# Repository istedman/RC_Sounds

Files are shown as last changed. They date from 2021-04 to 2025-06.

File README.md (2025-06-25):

# RC Sounds
A simple, low cost sound effect module for R/C vehicles, land or water based. It utilises a DF Robot DFR0299 MP3 module to continuously play a selected MP3 sound file. A Microchip ATTiny85 provides MP3 control functions, error handling and can support two servo PWM inputs. A set of 4 switches are used to provide easy selection of the desired sound sample. Using one of the PWM inputs, a horn/siren sound can be overlaid and once it finishes playing, normal sound resume. The horn/siren setting is programmable to allow for different receiver outputs.

A PAM8403 Class D amplifier, with EMC fixes is also provided, this allows the system to drive 2x 8 ohm speakers at 2W. Volume control is provided on-board as well as an option to mute the amplifier and finally use an external amplifier, if desired using the pre-amp outputs.

PCB designed to fit into a Hammond 1594B enclosure.
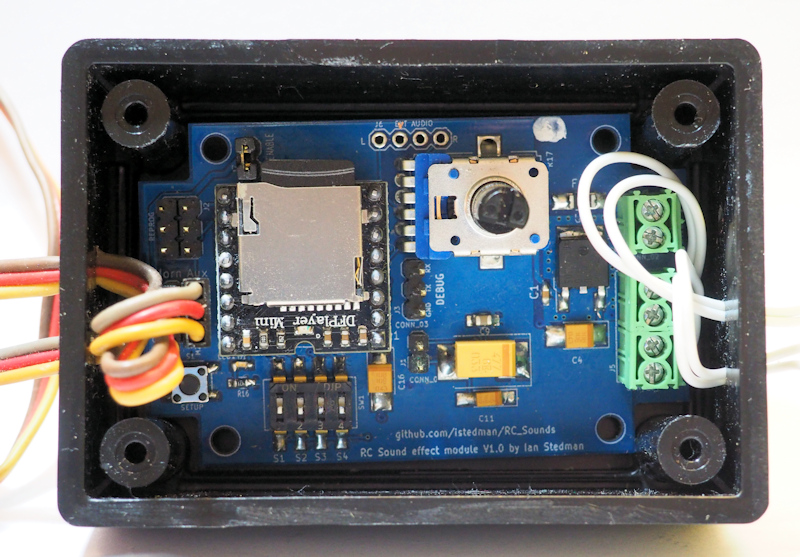
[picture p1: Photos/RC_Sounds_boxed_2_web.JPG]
Boxed unit


Total cost of all parts, PCB, enclosure and speakers is approximately £30. See the BOM directory for an HTML export with full ordering part numbers.

## Current state as of 25th June 2025.
Design is working well. Has based compatibility tests with multiple AM/2.4 GHz receivers, 2-6 channels and has been field tested.

Use the updated V1.2_1_int software, this adds 4 speeds to the engine sounds and utilises the auxilary input to act as the throttle. The software is written in the Arduino IDE, it uses the ATtinyCore library and no bootloader. The board must be programmed using a progammer, I use a USBASP. To allow the PWM settings function to work, you have to disable the reset function on the fuses. A high voltage programmer is required to unlock. I use this design, https://github.com/wokwi/attiny-hvsp-programmer and clip onto the ATTiny85. All fuse setting defined in the software.

ATTiny85 fuse settings are in the header of the main source code, use USBASP/Avrdudess to set them.

## Boat sound effects SD card image now available

My example SD card image, for boats has now been uploaded to the repository.

## Powering the design

Power is from a 3.7-12V supply or the receiver BEC circuit. Unit has a polyfuse to protect against reverse polarity and a linear regulator.
Do not use with a 1S LiPO ESC or any other ESC that boosts the BEC output. The current design assumes the stndard +5V BEC output voltage. My 1S LiPO ESCs output
6 or 7.2V to boost the servo power, using such an ESC (Trackstar Gen II 120A or Hobbywing Xerun) would irreprably damage the design as it will operate with 5.5V maximum.

You will need an UltraBEC/SuperBEC ESC, i.e. one that can output 2A @ 5V for reliable operation. This unit can demand a peak 0.6A @ 5V, when tested with a 1A BEC, and 3-4 servos, I had a few brownouts. If it reandomly resets at the same time as your receiver, use the external power option and remove the BEC jumper!

## Schematic and circuit description

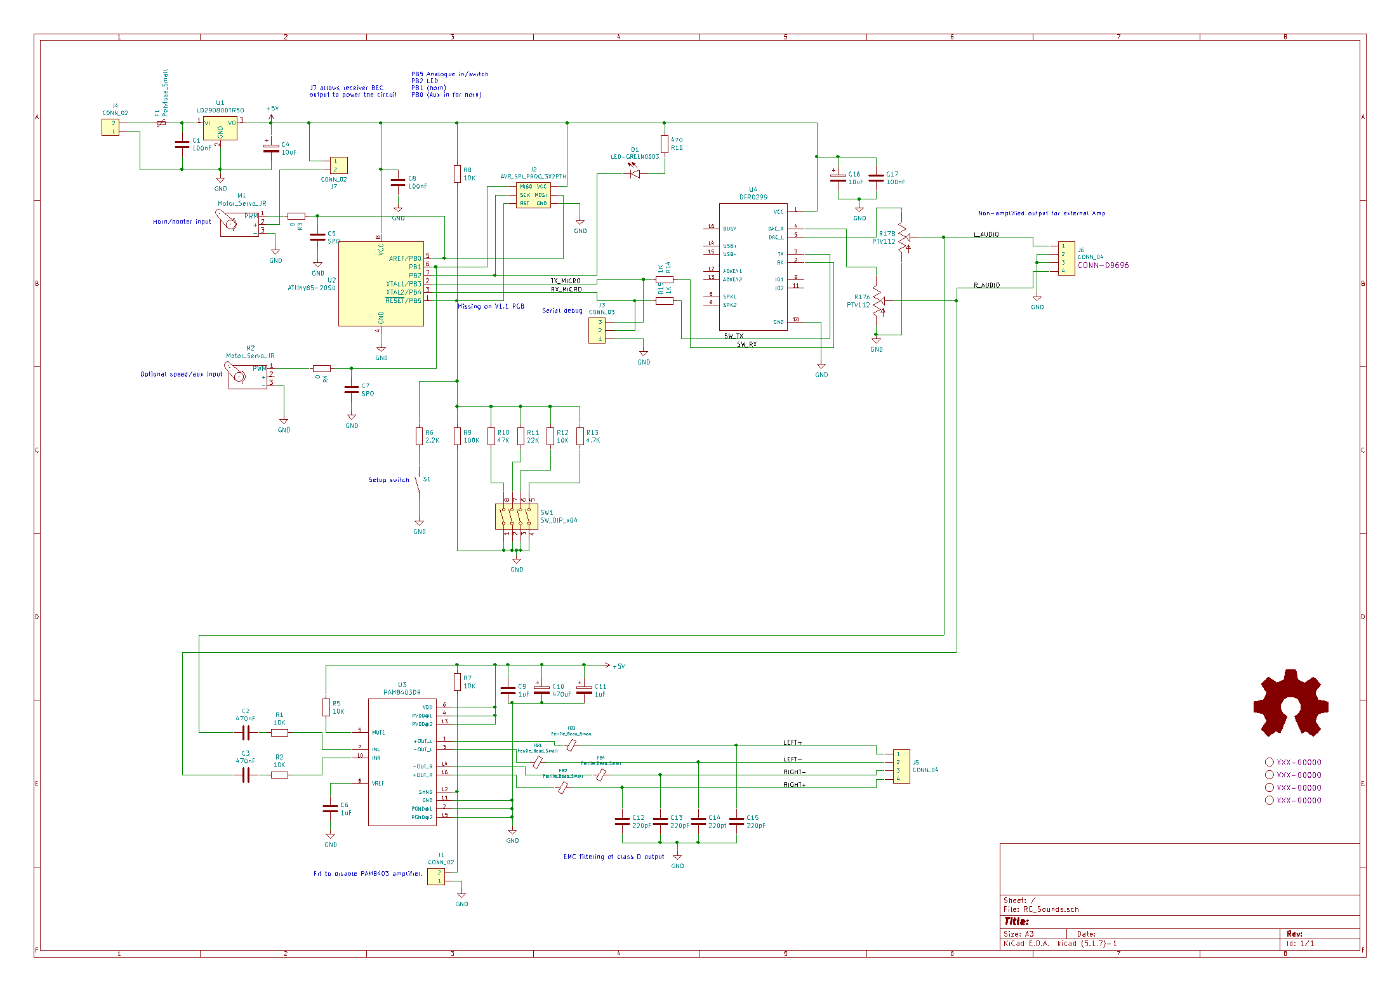
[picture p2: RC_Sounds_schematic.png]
Schematic


Power comes from the 5V BEC output of the ESC, if you fit a jumper on J7 of from a 3.7-12V source via J2, using appropriate wire. Connections via J2 have a 1.1A polyfuse and a LD29080-5 5V, 800mA LDO regulator, which provde revers polarity protection.

The ATTiny 85 microcontroller provides the control function. It reads the PWM inputs from two receiver channels, the horn/hooter input connects to pin 5 and the throttle input connects to pin 6. 

Communications to/from the DFR0299 MP3 module are via pins 2 & 3 and use a standard 9600 8N1 serial interface. A USB to TTL adaptor can be connected to the TX output of the ATTiny 85 on pin 2 for debug messages, using J3.

A solitary LED, D1 is used to setup functions and when the horn has been activated.

A set of DIP switches, SW1, set various analogue voltages that determine the sound sample to be played. Limits are defined in the software. A setup switch, S1 is used in the setup routine to set the horn on/off position and the throttle positions.

The DAC output of the DFR0299 is connected, via a dual gang audio potentiometer R17A/B to a PAM8403 audio amplifier. J6 provides a pre-amplifier output.
The DFR0299 DAC outputs, post volume control are AC coupled via C2 and C3. Connector J1 can be used to mute the amplifier. Capacitor C10, a 47uF capacitor, is to reduce the effects of the amplifier on the power supplies. I have added the recommended filter circuit to the output stage, using FB1-FB4 and C12-C15, this reduces radio emissions in the region of 25-40 MHz, important for RC usage as there are still some 27 and 40 MHz systems around.

Into 8 ohm speakers the design can deliver 1.8W. Peak power i've observed has been close to 2W.

A photo of the PCB
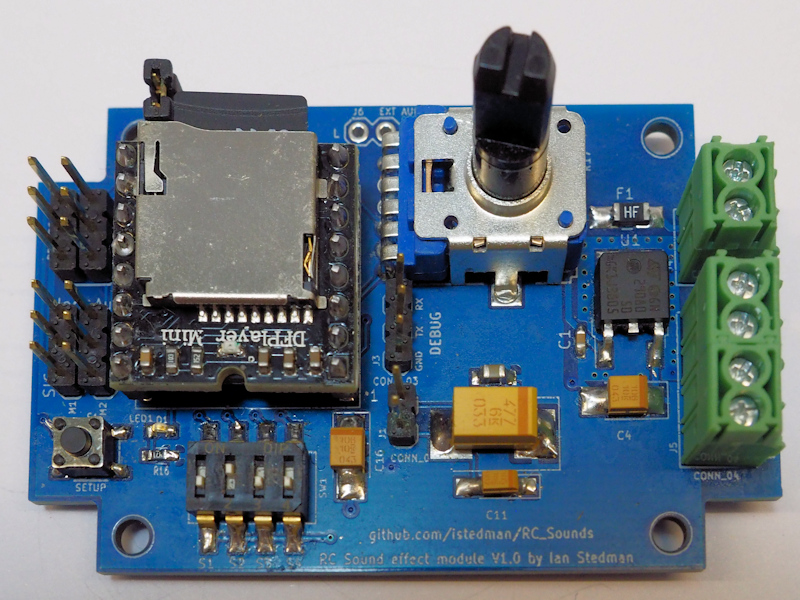
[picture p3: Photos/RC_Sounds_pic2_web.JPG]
Just the PCB


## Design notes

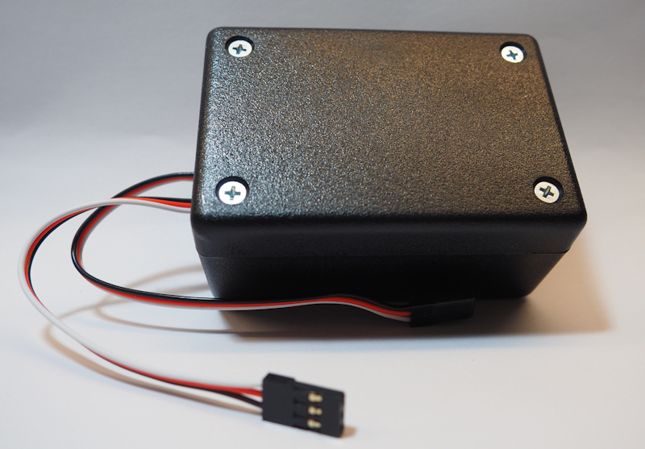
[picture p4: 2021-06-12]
Photos/RC_Sounds_boxed_1_web.JPG

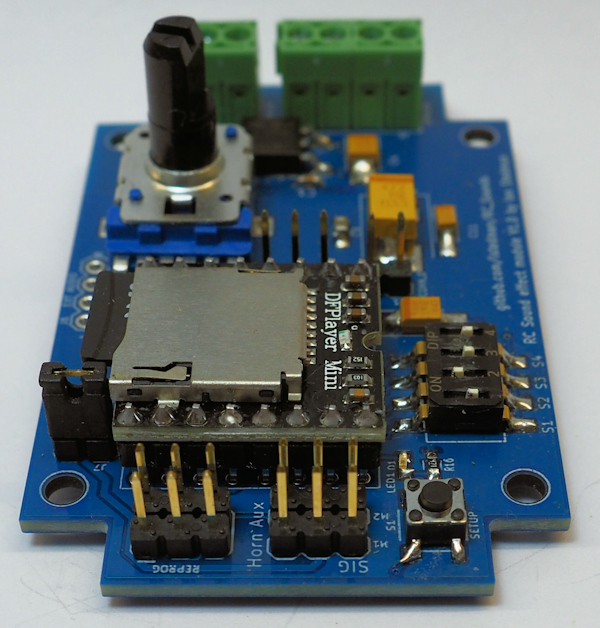
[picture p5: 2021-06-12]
Photos/RC_Sounds_pic3_web.JPG

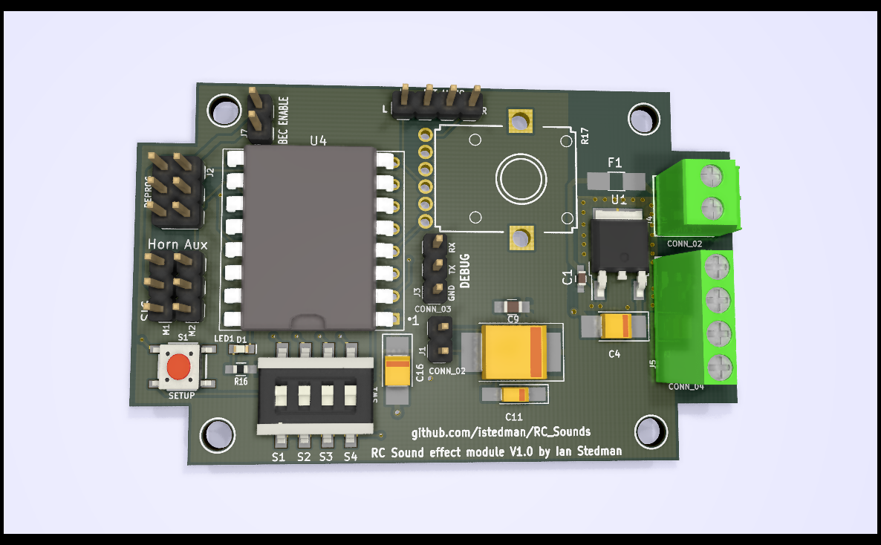
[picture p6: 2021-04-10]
RC_Sounds_3d_PCB.png

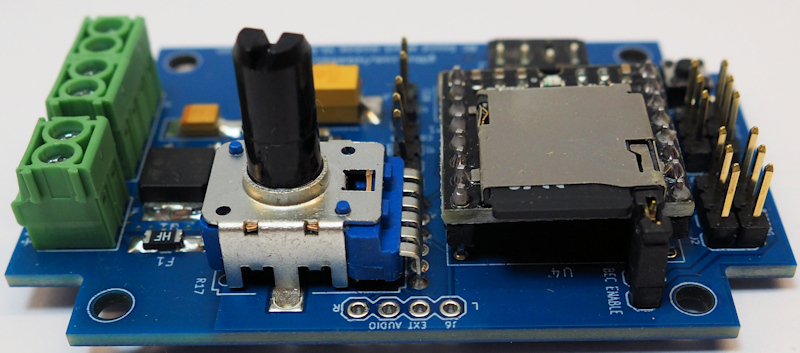
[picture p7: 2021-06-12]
Photos/RC_Sounds_pic1_web.JPG

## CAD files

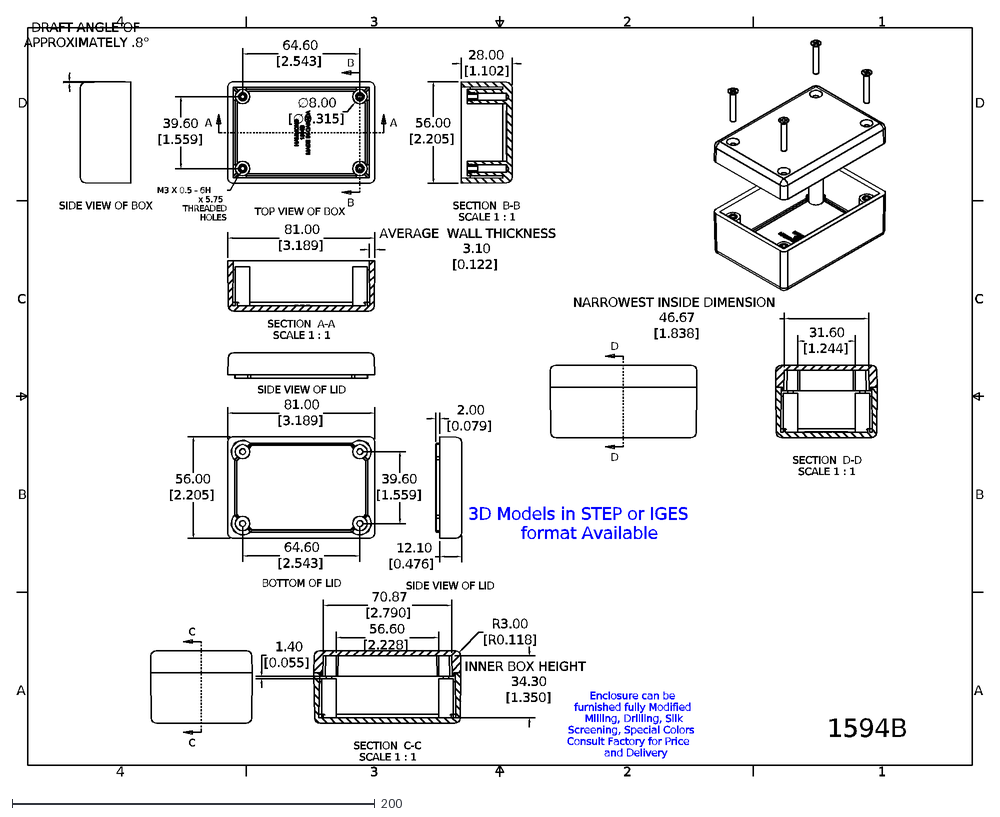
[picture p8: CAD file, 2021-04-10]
1594B.dxf
TOP VIEW OF BOX
BOTTOM OF LID
SIDE VIEW OF BOX
A
SECTION A-A
SCALE 1 : 1
B
SECTION B-B
64.60
[2.543]
39.60
[1.559]
∅8.00
[∅0.315]
DRAFT ANGLE OF
APPROXIMATELY .8°
81.00
[3.189]
AVERAGE WALL THICKNESS
3.10
[0.122]
56.00
[2.205]
28.00
[1.102]
SIDE VIEW OF LID
M3 X 0.5 - 6H
x 5.75
THREADED
HOLES
2.00
[0.079]
12.10
[0.476]
C
SECTION C-C
1.40
[0.055]
56.60
[2.228]
70.87
[2.790]
INNER BOX HEIGHT
34.30
[1.350]
R3.00
[R0.118]
D
SECTION D-D
31.60
[1.244]
NARROWEST INSIDE DIMENSION
46.67
[1.838]
1
2
3
4
1594B
Enclosure can be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

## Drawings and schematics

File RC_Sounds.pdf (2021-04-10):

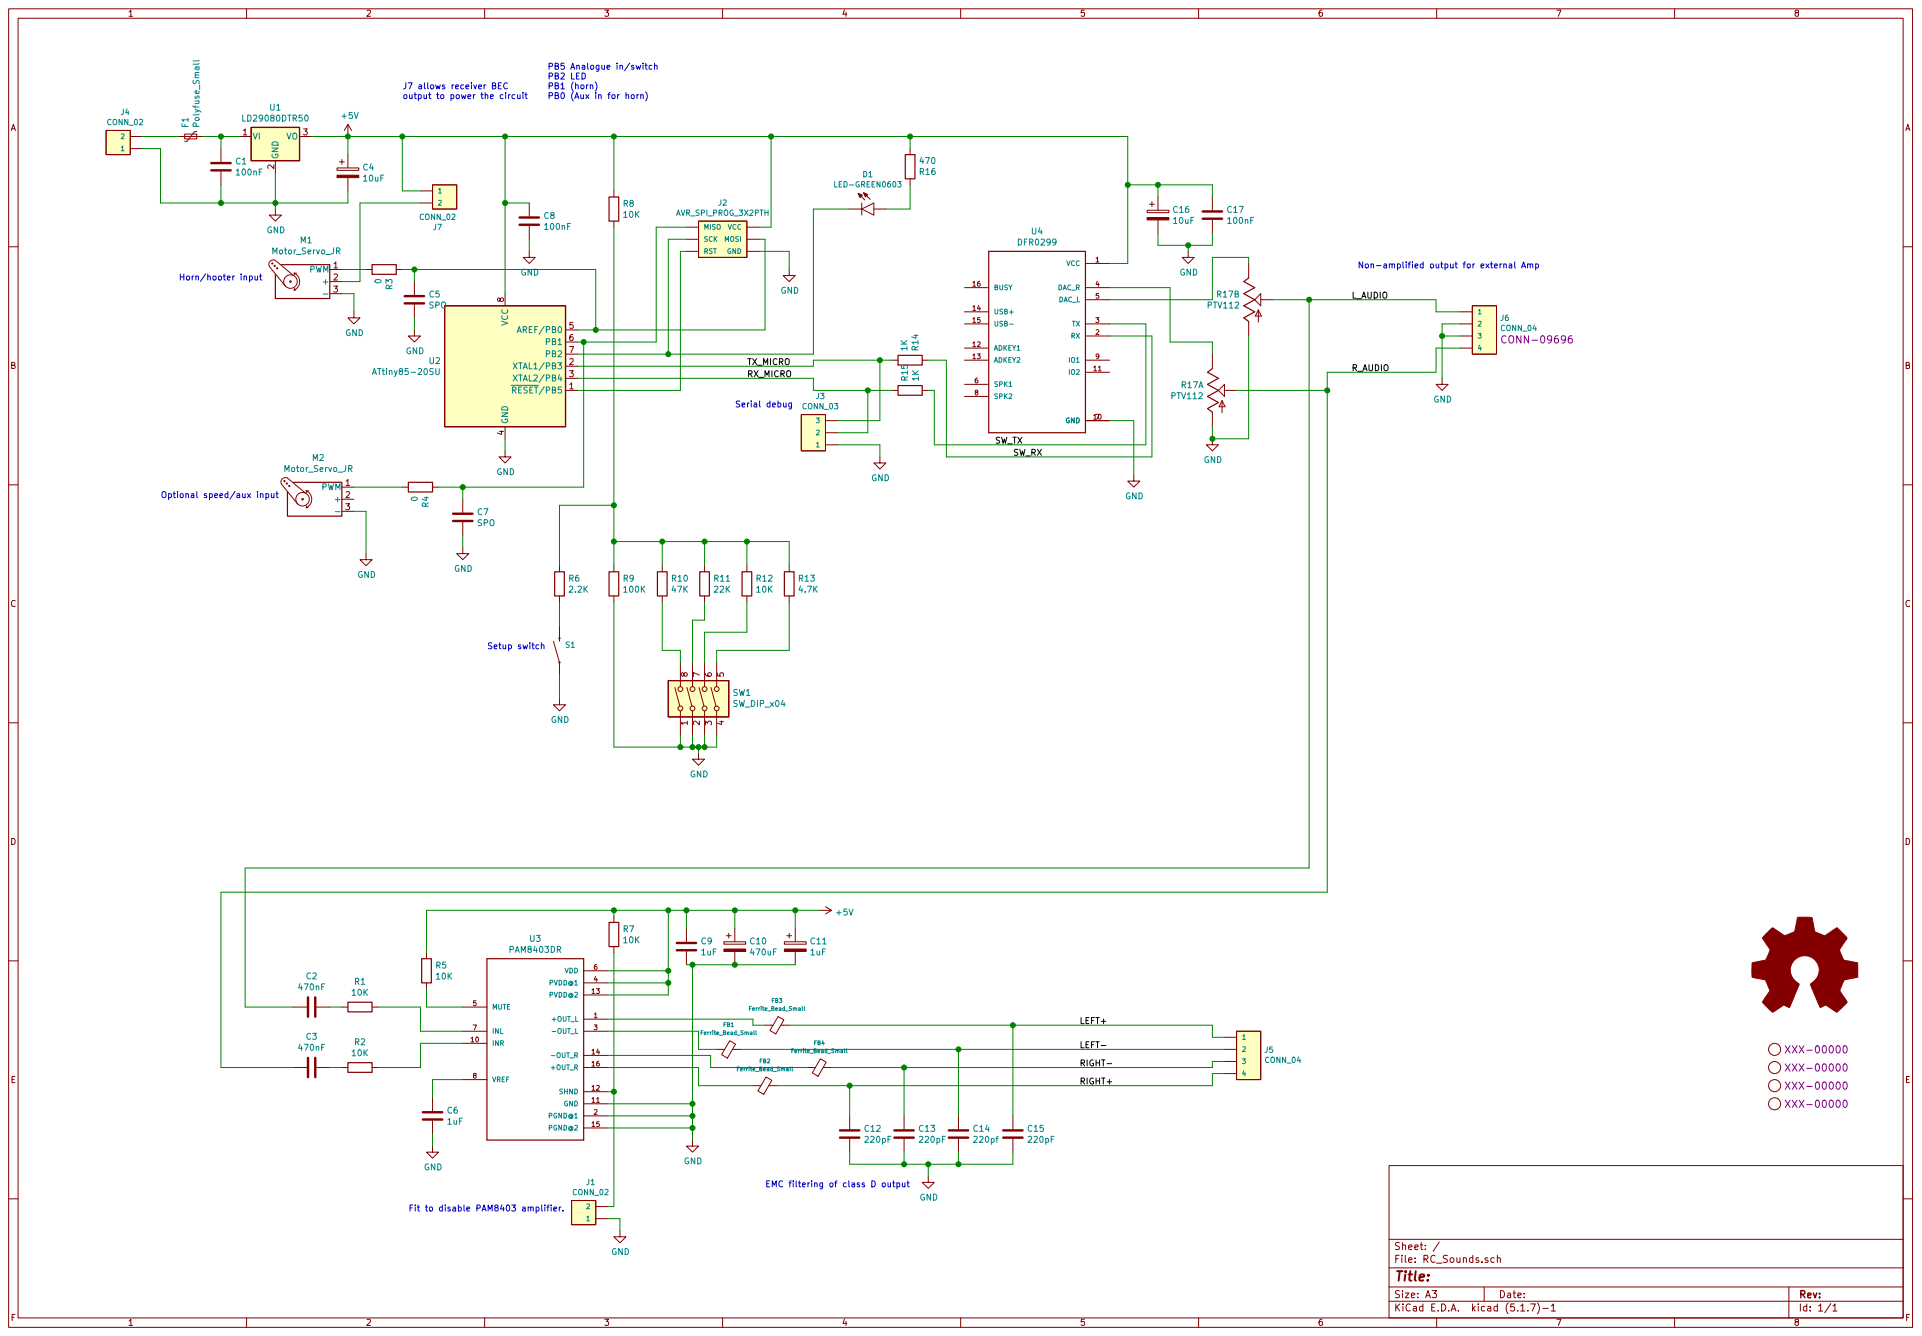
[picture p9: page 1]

PB5 Analogue in/switch PB2 LED

J7 allows receiver BEC
output to power the circuit

Non-amplified output for external Amp

Optional speed/aux input

EMC filtering of class D output

Fit to disable PAM8403 amplifier.

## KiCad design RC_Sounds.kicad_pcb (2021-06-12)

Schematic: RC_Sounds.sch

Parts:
C1, C8, C17: 100nF; C_0603_HandSoldering
C2, C3: 470nF; C_0603_HandSoldering
C4, C16: 10uF; CP_Tantalum_Case-B_EIA-3528-21_Hand
C5, C7: SPO; C_0603_HandSoldering
C6, C9: 1uF; C_0805_HandSoldering
C10: 470uF; CP_Tantalum_Case-E_EIA-7260-38_Hand
C11: 1uF; CP_Tantalum_Case-A_EIA-3216-18_Hand
C12, C13, C15: 220pF; C_0603_HandSoldering
C14: 220pf; C_0603_HandSoldering
D1: LED-GREEN0603; LED-0603
F1: Polyfuse_Small; Fuse_SMD1206_HandSoldering
FB1, FB2, FB3, FB4: Ferrite_Bead_Small; R_0805
H1, H2, H3, H4: STAND-OFFTIGHT; STAND-OFF-TIGHT
J1, J7: CONN_02; 1X02
J2: AVR_SPI_PROG_3X2PTH; 2X3
J3: CONN_03; 1X03
J4: CONN_02; SCREWTERMINAL-3.5MM-2
J5: CONN_04; SCREWTERMINAL-3.5MM-4
J6: CONN_04; 1X04
M1, M2: Motor_Servo_JR; 1X03
R1, R2, R5, R7, R8, R12: 10K; R_0603_HandSoldering
R3, R4: 0; R_0603_HandSoldering
R6: 2.2K; R_0603_HandSoldering
R9: 100K; R_0603_HandSoldering
R10: 47K; R_0603_HandSoldering
R11: 22K; R_0603_HandSoldering
R13: 4.7K; R_0603_HandSoldering
R14, R15: 1K; R_0603_HandSoldering
R16: 470; R_0603_HandSoldering
R17: PTV112
S1: MOMENTARY-SWITCH; TACTILE_SWITCH_SMD_5.2MM
SW1: SW_DIP_x04; DIPSWITCH-04-SMD
U1: LD29080DTR50; TO-252-2
U2: ATtiny85-20SU; SOIC-8-N
U3: PAM8403DR; SO-16-N
U4: DFR0299; MODULE_DFR0299

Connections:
+5V: C4.1, C8.1, C9.1, C10.1, C11.1, C16.1, C17.1, J2.2, J7.1, R5.1, R7.1, R8.1, R16.2, U1.3 (VO), U2.8, U3.4, U3.6, U3.13, U4.1
/LEFT+: C15.1, FB3.2, J5.1
/LEFT-: C14.1, FB1.2, J5.2
/L_AUDIO: C2.1, J6.1, R17.2.2
/RIGHT+: C12.1, FB2.2, J5.4
/RIGHT-: C13.1, FB4.2, J5.3
/RX_MICRO: J3.2, R15.1, U2.3
/R_AUDIO: C3.1, J6.4, R17.1.2
/SW_RX: R14.1, U4.2
/SW_TX: R15.2, U4.3
/TX_MICRO: J3.3, R14.2, U2.2
GND: C1.2, C4.2, C5.2, C6.2, C7.2, C8.2, C9.2, C10.2, C11.2, C12.2, C13.2, C14.2, C15.2, C16.2, C17.2, J1.1, J2.6, J3.1, J4.1, J6.2, J6.3, M1.3 (-), M2.3 (-), R9.2, R17.1.1, R17.2.1, S1.1, SW1.1, SW1.2, SW1.3, SW1.4, U1.2 (GND), U2.4, U3.2, U3.11, U3.15, U4.7, U4.10
unnamed: C1.1, F1.2, U1.1 (VI)
unnamed: C2.2, R1.1
unnamed: C3.2, R2.1
unnamed: C5.1, J2.4, R3.1, U2.5
unnamed: C6.1, U3.8
unnamed: C7.1, J2.1, R4.1, U2.6
unnamed: D1.A, R16.1
unnamed: D1.C, J2.3, U2.7
unnamed: F1.1, J4.2
unnamed: FB1.1, U3.3
unnamed: FB2.1, U3.16
unnamed: FB3.1, U3.1
unnamed: FB4.1, U3.14
unnamed: J1.2, R7.2, U3.12
unnamed: J2.5, R6.1, R8.2, R9.1, R10.1, R11.1, R12.1, R13.1, U2.1
unnamed: J7.2, M1.2 (+)
unnamed: M1.1 (PWM), R3.2
unnamed: M2.1 (PWM), R4.2
unnamed: R1.2, U3.7
unnamed: R2.2, U3.10
unnamed: R5.2, U3.5
unnamed: R6.2, S1.3
unnamed: R10.2, SW1.8
unnamed: R11.2, SW1.7
unnamed: R12.2, SW1.6
unnamed: R13.2, SW1.5
unnamed: R17.1.3, U4.4
unnamed: R17.2.3, U4.5

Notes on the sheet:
Fit to disable PAM8403 amplifier.
EMC filtering of class D output
Non-amplified output for external Amp
PB5 Analogue in/switch PB2 LED PB1 (horn) PB0 (Aux in for horn)
Setup switch
Horn/hooter input
Optional speed/aux input
J7 allows receiver BEC output to power the circuit
Serial debug
Missing on V1.1 PCB

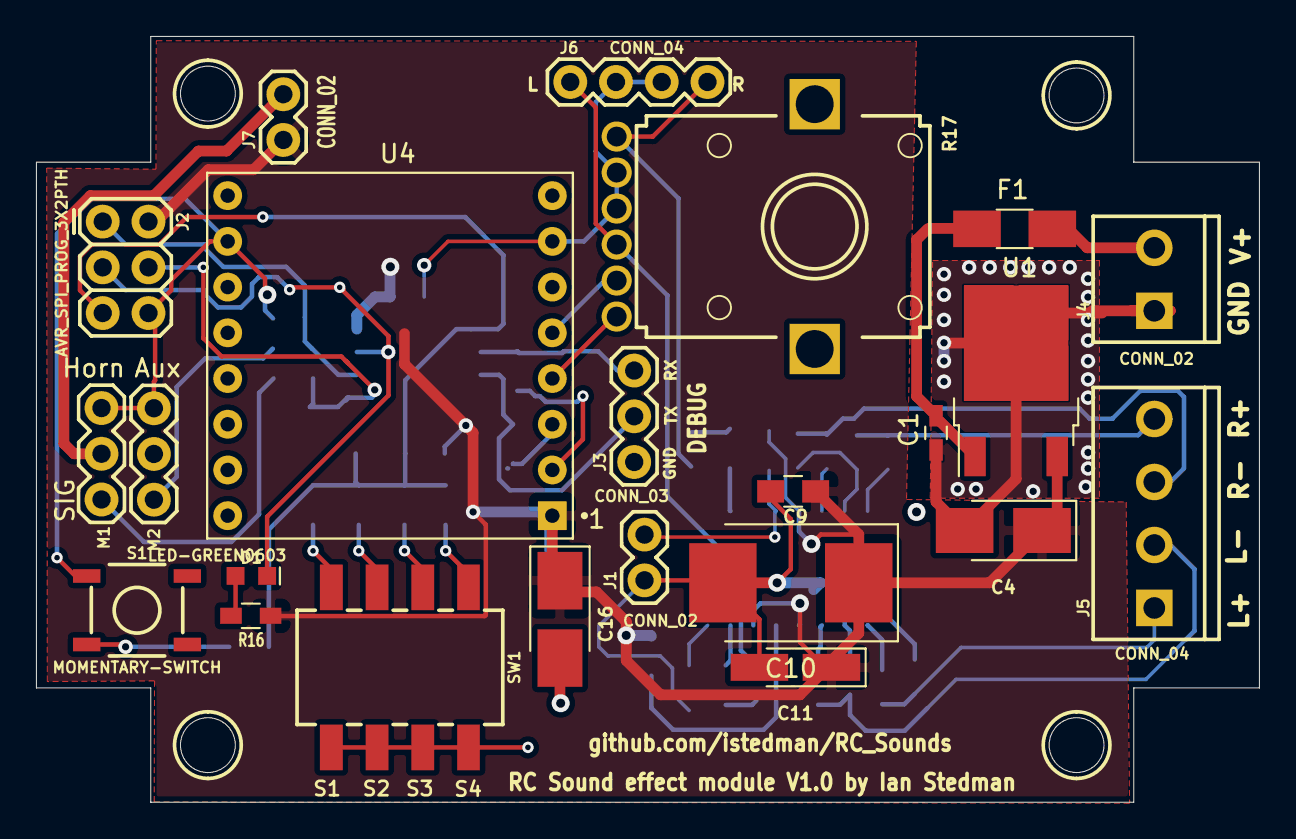
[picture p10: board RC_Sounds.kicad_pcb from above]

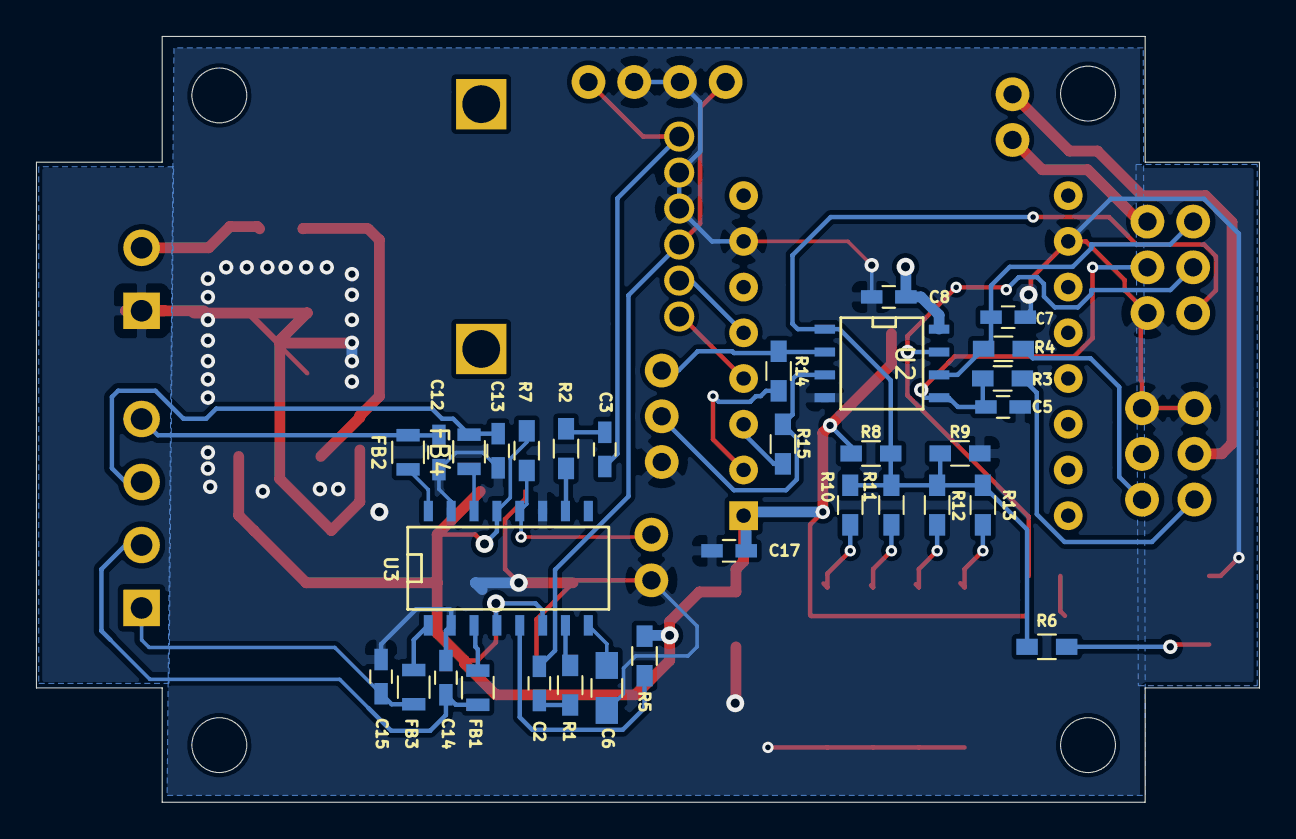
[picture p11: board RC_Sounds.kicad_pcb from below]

Board: 2 copper layers, 67.9 x 42.5 mm, 59 parts (32 on the bottom side), 40 nets.

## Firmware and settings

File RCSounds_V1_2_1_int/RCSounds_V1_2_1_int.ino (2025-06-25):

/*
 * RC Sounds Software
 * Version          1.2.1
 * Date             7th August 2023
 * Target & config  ATTiny 85 with no bootloader, 16MHz PLL, B.O.D. disabled, Timer1 clock set to CPU.
 *                  LTO set to enabled, Millis()/Micros() set to enabled.Save EEPROM set to 'Not retained'
 *                  Progrmmer USBAsp
 * Fues             Low       0xD1   /F1 Need 64ms startup timer when RSTDISBL turned on to allow for PSU 
 *                                   slow ramp. Fixed startup issues I experienced.
 *                  High      0xDF for development but use 0x5F for final, this disables reset so need high voltage programming to remove.
 *                  Extended  0xFF  Don't need self programming as there is no bootloader.
 *                  LB        0xFF
 * Pinout and I/O   PB0       Servo PWM input
 *                  PB1       Throttle input
 *                  PB2       LED, active low
 *                  PB3       Serial TX pin to MP3 module
 *                  PB4       Serial RX pin from MP3 module
 *                  PB5/A0    Analgue input, reset disabled, also has setup switch.
 * 
 * Description
 *                  This software controls  DFRobot DFR0299 Mini MP3 player using a software serial port. It is used to create a sound effects module 
 *                  for radio control vehicles.
 *                  Currently used for boats but could be used for cars or planes. It is fixed pitch so cannot change as speed increases.
 *                  There is the option to have a horn sound effect. This is achieved by mixing the continuous engine sound and a pre-determined 
 *                  horn sample. To play the horn the software switches to an advert, this allows a quick selection of another audio track.
 *                  The analogue input connects to 4 switches via a resistive divider, this allows easy selection of the sound effect in the field.
 *                  
 *                  You can connect a TTL serial cable to the RX pin and GND, to monitor the debug messages.
 *                  The MP3 module ignores all text strings.
 *             
 */

#include <DFPlayerMini_Fast.h>
#include "RC_Sounds.h"
#include <EEPROM.h>
#include <SoftSerial.h>     /* Allows Pin Change Interrupt Vector Sharing */

SoftSerial mySerial(4, 3); // RX, TX for the MP3 module

/*  
  SoftRcPulseIn HornIn;
  SoftRcPulseIn ThrotIn;
  */

/*
 * ALL SETUP IS DONE IN RC_Sounds.h, edit that to define the configuration
 */

//DFRobotDFPlayerMini myMP3;
DFPlayerMini_Fast myMP3;

//Best keeping this here as it's easy to change.
//#define DEBUG 33
//#define DEBUGPROG 1
//#define ERASESETTINGS 2
/*
 * Intialise the hardware, configuring the I/O as required 
 * Moved MP3 player init to the end to allow for other setup first.
 * 
 */

void setup()
{
  pinMode(LEDPIN,OUTPUT);
  digitalWrite(LEDPIN,LEDON);       // Switch LED on until MP3 initialised and playing
  mySerial.begin(9600);             // My debug software serial.
  myMP3.begin(mySerial);
  delay(1000);                      // Give it time to initialise
  myMP3.volume(28);                 // Maximum value without distortion
  pinMode(HORN_IN, INPUT_PULLUP); 
  pinMode(THROTTLE_IN,INPUT_PULLUP);

  Scaled_V=AvgADCRead(SELECTION_IN);
  if (Scaled_V>SETUP_LOWER && Scaled_V<SETUP_UPPER)
  {
    DoSetup();
  }
  /*
   * See if the letter 'T' has been stored, indicating valid data has been set by the user.
   * If it has, recall the settings to globals.
   */
  #ifndef ERASESETTINGS
  if (EEPROM.read(E_INIT) == 'T')
  {
    RecallSettings();
    CalculateGears();
  }
  #endif
  else{  /* First run through of the software, reset to default values by calling the function below */
      ResetSettings();
      RecallSettings();
      CalculateGears();
   }
    digitalWrite(LEDPIN,LEDOFF);       // Switch LED off now init is complete
    PWMFound=CheckforPWMInputs();      // Save unnecessary waits for PWM inputs later on.
    // For maintenance only and not in debug mode
    #ifndef DEBUG
    GetCurrentPWMVals();
    mySerial.println(F("\nEEPROM Settings:"));
    mySerial.print(F("Forward Throttle limit "));
    mySerial.println(ForwardThrot);
    mySerial.print(F("Neutral "));
    mySerial.println(NeutralThrot);
    mySerial.print(F("Reverse Throttle limit "));
    mySerial.println(ReverseThrot);
    mySerial.print(F("Throttle is "));
    if (ThrotNormReverse==NORMAL_THROT)
    {
      mySerial.println(F("normal."));
    }
    else
    {
      mySerial.println(F("reversed."));
    }
    mySerial.print(F("Horn limit "));
    mySerial.print(HornPulseLimit);
    mySerial.print(F(", must be "));
    if (HornGreatOrLessThan == GREATERTHAN)
    {
      mySerial.println(F(" > to operate."));
    }
    else
    {
      mySerial.println(F(" < to operate"));
    }
    mySerial.print(F("PWM detected:"));
    if (PWMFound==1 || PWMFound== 11)
    {
      mySerial.println(F("Horn OK "));
      mySerial.print(F("Current horn "));
      mySerial.println(HornPWM);      
    }
    if (PWMFound==10 || PWMFound== 11)
    {
      mySerial.println(F("Throttle OK "));
      mySerial.print(F("Current throttle "));
      mySerial.println(ThrottlePWM);
    }
    else
    {
      mySerial.println(F("No PWM found"));
    }
    #endif
    RunTime=millis();
}

byte CalculateGears(void)
{
   unsigned int GearCalc=0;
   if(ThrotNormReverse==NORMAL_THROT)
      {
          GearCalc=(ForwardThrot-NeutralThrot)/4;    // Get the difference and divide by 4
          FirstGear=NeutralThrot+GearCalc; 
          SecondGear=FirstGear+GearCalc;      
          ThirdGear=SecondGear+GearCalc;
          FourthGear=ThirdGear+GearCalc;
      }
      else if (ThrotNormReverse==REVERSE_THROT)
      {
          GearCalc=(NeutralThrot-ForwardThrot)/4;    // Get the difference and divide by 4
          FirstGear=NeutralThrot-GearCalc; 
          SecondGear=FirstGear-GearCalc;      
          ThirdGear=SecondGear-GearCalc;
          FourthGear=ThirdGear-GearCalc;
      }
      #ifdef DEBUG
      mySerial.print(F("Gears 1: "));
      mySerial.print(FirstGear);
      mySerial.print(F(" 2: "));
      mySerial.print(SecondGear);
      mySerial.print(F(" 3: "));
      mySerial.print(ThirdGear);
      mySerial.print(F(" 4: "));
      mySerial.print(FourthGear);
      mySerial.print(F(" Max: "));
      mySerial.print(ForwardThrot);
      mySerial.print(F(" Neutral: "));
      mySerial.print(NeutralThrot);
      mySerial.print(F(" Reverse: "));
      mySerial.println(ReverseThrot);
      #endif
      CurrentGear=0; // For initialisation to be sure in case PWM count is way off.
}

/*
 * Function to recall all settings from EEPROM and initilise the global variables.
 *  Easier to do this as I only have to concatenate two
 * bytes from EEPROM once. If read from EEPROM, would do this every time around loop.
 */
byte RecallSettings(void)
{
      byte LimLo,LimHi;
      
      LimLo=EEPROM.read(HORN_EEPROM_LO);
      LimHi=EEPROM.read(HORN_EEPROM_HI);
      HornPulseLimit=LimHi<<8 | LimLo;
      HornGreatOrLessThan=EEPROM.read(HORN_EEPROM_GT_LT);
      //Now read the throttle settings from EEPROM
      LimLo=EEPROM.read(THROT_EEPROM_FORWARD_LO);
      LimHi=EEPROM.read(THROT_EEPROM_FORWARD_HI);
      ForwardThrot=LimHi<<8 | LimLo;
      LimLo=EEPROM.read(THROT_EEPROM_NEUTRAL_LO);
      LimHi=EEPROM.read(THROT_EEPROM_NEUTRAL_HI);
      NeutralThrot=LimHi<<8 | LimLo;
      LimLo=EEPROM.read(THROT_EEPROM_REVERSE_LO);
      LimHi=EEPROM.read(THROT_EEPROM_REVERSE_HI);
      ReverseThrot=LimHi<<8 | LimLo;     
      ThrotNormReverse=EEPROM.read(THROT_EEPROM_DIRECTION);
}

     /*
     * For a first time, so store data in EEPROM, 1500us pulse width and Greater than for Horn. This gets around the issue
     * that the Arduino IDE/USBAsp cannot init EEPROM by default when programming a fresh device.
     *  Also store default throttle settings, idle of 1500us, full throttle of 2000us and reverse of 1000us.
     *  Also called if the user holds the setup button for 10 seconds
      */
int ResetSettings(void)
{
  
    EEPROM.write(HORN_EEPROM_LO,0xD0);
    EEPROM.write(HORN_EEPROM_HI,0x07); // 0x7d0 = 2000 (us)
    EEPROM.write(HORN_EEPROM_GT_LT,GREATERTHAN);
    //Now store the default throttle settings
   
    EEPROM.write(THROT_EEPROM_FORWARD_LO,0xD0);
    EEPROM.write(THROT_EEPROM_FORWARD_HI,0x07); // 0x7D0 = 2000 (us)
    EEPROM.write(THROT_EEPROM_NEUTRAL_LO,0xDC);
    EEPROM.write(THROT_EEPROM_NEUTRAL_HI,0x05); // 0x5DC = 1500 (us)
    EEPROM.write(THROT_EEPROM_REVERSE_LO,0xE8);
    EEPROM.write(THROT_EEPROM_REVERSE_HI,0x03); // 0x3E8 = 1000 (us)
    EEPROM.write(THROT_EEPROM_DIRECTION,NORMAL_THROT);
    EEPROM.write(E_INIT,'T');
    //A little LED flash or 4 to indicate settings reset
    BlinkLED(4, 700, 300);
}
/* 
   This checks the PWM input pulse and will play the mixed horn sample if detected width matches the value in EEPROM
   The second method, will be used on the model, it reads width of the PWM pulse and if is within a window of values, 
   changes the MP3 track to an advert
*/
int PlayHorn()
{
    unsigned int HornTime;
    HornTime=HornPWM;
    CurrentAdvert=SpeedIndex[Sounds][CurrentGear];

    if(HornTime >500 && HornTime <2500) // To detect lack of signal or seriously large signal and not toot your trumpet
    {
      
        if((HornGreatOrLessThan==GREATERTHAN && HornTime > HornPulseLimit) || (HornGreatOrLessThan==LESSTHAN && HornTime < HornPulseLimit))
        {
          if (CurrentAdvert != PreviousAdvert)
          {
              myMP3.playAdvertisement(CurrentSound);
              AdvertPlaying=1;    // Used to stop advert interruption
              AdTime=millis();
              digitalWrite(LEDPIN,LEDON);   // Now switch the LED on to indicate we have detected a valid input.
          }
              PreviousAdvert=CurrentAdvert;    
        }
    }
    /* After 13 seconds, we need to assume the horn input has gone and switch off the LED
     * and reset previous advert.
     */
     /*TimeSinceAd=millis();
       if (TimeSinceAd > AdTime+ 3000)
       */
       if(millis() >(AdTime+13000))
       {
          digitalWrite(LEDPIN,LEDOFF);  // Signal end of HORN/Advert.
          PreviousAdvert=0;
          AdvertPlaying=0;
       }
} // End PlayHorn function



/*
 * Function to take 4 readings from the specified ADC channel, average them, convert to a voltage
 * and return it to the calling function.
 */

//float AvgADCRead(byte ADCInput)
unsigned int AvgADCRead(byte ADCInput)
{
  unsigned int AvgADC=0;
  byte loopCNT=0;
  //float AvgADCVal=0.0;
  unsigned int AvgADCVal=0;
  
  for(loopCNT=0;loopCNT<4;loopCNT++)
  {
    AvgADC=AvgADC+analogRead(ADCInput);
    delay(2);   // ADC settle time
  }
  AvgADCVal= AvgADC>>2;   // Calculate average of 4 readings
  return(AvgADCVal);
}

/*
 * Function to read the analogue input and see if the voltage matches the expected range of the setup switch.
 * Will return SWITCHPRESSED or SWITCHOPEN in response
 */

byte ReadSetupSwitch()
{
  unsigned int ADCReading;
  ADCReading=AvgADCRead(SELECTION_IN);
  if (ADCReading >SETUP_LOWER && ADCReading < SETUP_UPPER)
  {
    return(SWITCHCLOSED);
  }
  else
  {
    return(SWITCHOPEN);
  }
}

/*
 * Function to check if one or both PWM inputs are active in the setup phase.
 * It calls pulsein() on both potential inputs, looks for non-zero response and then returns 1 of 4 codes 
 * Return codes
 * 0    No pwm input
 * 1    Horn input only
 * 10   Throttle input only
 * 11   Horn and throttle present
 * ONLY USED IN SETUP NOW
 */

byte CheckforPWMInputs(void)
{
  int pwm1,pwm2;
  byte pwmfound=0;

  pwm1=pulseIn(HORN_IN,HIGH);
  pwm2=pulseIn(THROTTLE_IN,HIGH);
/*
 pwm1=HornIn.width_us();
 pwm2=ThrotIn.width_us();
 */
  if(pwm1>800 && pwm1 <2500)
  {
    pwmfound=1;   // Found horn PWM
  }
  if (pwm2>800 && pwm2 <2500)
  {
    pwmfound+=10; // Found throttle PWM
  }
  return(pwmfound); // Return result. Is initialised to zero in case no signals found
}

/* Function to do the setup for a simple on/off switch.
 * Hold down the setup switch to enter, release it to start the setup.
 * Use the pulseIN() function to read the PWM inputs
 * It can work with greater than a pulse limit or less than a pulse limit. This is stored in EEPROM
 * As we are reading an analogue input, which uses a push switch, looking for >SETUP_LOWER & <SETUP_HIGHER, 
 * we still need to debounce.
 *
 */ 
int DoSetup()
{
    unsigned long Timeout1=0, Timeout2=0;
    byte Dbounce1=0, Dbounce2=0;
    byte PWMAvailable=0;
    //float SetupSWVal=0.0;
    Dbounce1=ReadSetupSwitch();
    Timeout1=millis(); // read current time
    BlinkLED(6,300,300);
    //Wait for switch release
    do
    {
        Dbounce1=ReadSetupSwitch();
        delay(DEBOUNCETIME);
        Dbounce2=ReadSetupSwitch();
        Timeout2=millis();
        if (Timeout2-Timeout1 >10000)
        {
          #ifdef DEBUG
          mySerial.println(F("Reset settings in Dosetup"));
          #endif
          ResetSettings();
          return(77); // Exit out now.
        }
        
    }while(Dbounce1==SWITCHCLOSED && Dbounce1==SWITCHCLOSED);
    
    PWMAvailable=CheckforPWMInputs();

    switch (PWMAvailable){

      case 1:             // Horn only
        DoHornSetup();
      break;

      case 10:            // ThrottleOnly
        DoThrottleSetup();
      break;
      
      case 11:            // Both
        DoHornSetup();
        DoThrottleSetup();
      break;

      case 0:               // No PWM detected so abort
      default:
            BlinkLED(6, 200, 800);
            return(67);
            #ifdef DEBUG
            mySerial.print(F("No PWM in setup"));
            #endif
     
        break;

    }// End case
    // Back to main routine
    return(23);
}

/*
 * Function to read the PWM input from the horn and store the values in EEPROM.
 * Can handle normal or reverse PWM inputs
 */
byte DoHornSetup(void)
{
    unsigned int Pulse1, Pulse2;
    byte Byte1, Byte2;
    byte Dbounce1=0, Dbounce2=0;
    byte LED1=0;
    byte i=0;
    
    // First we need the off position, wait for user to press button
    do
    {
        Dbounce1=ReadSetupSwitch();
        delay(DEBOUNCETIME);
        Dbounce2=ReadSetupSwitch();        
    } while(Dbounce1==SWITCHOPEN && Dbounce2==SWITCHOPEN );

    Pulse1=pulseIn(HORN_IN, HIGH,22000);
    //Pulse1=HornIn.width_us();
    BlinkLED(1, 300, 300);

    //Now we need the full extent/on value, let user release switch
    do
    {
        Dbounce1=ReadSetupSwitch();
        delay(DEBOUNCETIME);
        Dbounce2=ReadSetupSwitch();        
    } while(Dbounce1==SWITCHCLOSED && Dbounce2==SWITCHCLOSED );      
 
    //Now move to final value and close switch.
    // Now we need the off position, wait for user to press button
    
     do
    {
        Dbounce1=ReadSetupSwitch();
        delay(DEBOUNCETIME);
        Dbounce2=ReadSetupSwitch();        
    } while(Dbounce1==SWITCHOPEN && Dbounce2==SWITCHOPEN );  
    
     Pulse2 = pulseIn(HORN_IN, HIGH,22000);   // get the timer value
     BlinkLED(2, 300, 300);
  
    /* We should have two pulse limits in pulse1 & pulse2
     * If we subtract pulse2 from pulse 1 and it is positive, we are looking for greater than pulse2-TimerAdjustment
     * so we store pulse2 and GREATERTHAN to EEPROM
     * otherwise if pulse2-pulse1 is negative, we are looking for less than pulse 2 so we store pulse2+TimerAdjustmen
     * and LESSTHAN to EEPROM
     */ 
 
    if(Pulse2>Pulse1)
    {
        Pulse2=Pulse2-TimerAdjustment;
        Byte1=(byte)(Pulse2&0xFF);
        Byte2=(byte)(Pulse2>>8);
        EEPROM.write(HORN_EEPROM_LO,Byte1);
        EEPROM.write(HORN_EEPROM_HI,Byte2);
        EEPROM.write(HORN_EEPROM_GT_LT,GREATERTHAN);
    }
    else if (Pulse1>Pulse2)
    {
        Pulse2=Pulse2+TimerAdjustment;
        Byte1=(byte)(Pulse2&0xFF);
        Byte2=(byte)(Pulse2>>8);
        EEPROM.write(HORN_EEPROM_LO,Byte1);
        EEPROM.write(HORN_EEPROM_HI,Byte2);
        EEPROM.write(HORN_EEPROM_GT_LT,LESSTHAN);
    }
     return(1);
} // End DoHornSetup()

/*
 * Function to read the PWM input from the throttle and store the values in EEPROM.
 * Can handle normal or reverse PWM inputs. We have to detect and store neutral, full forward throttle and full reverse throttle
 */
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
void loop()
{
    //First check the switches input to know what sample to play
    
    Scaled_V=AvgADCRead(SELECTION_IN);
    GetCurrentPWMVals();
    CurrentGear=CheckCurrentGear();
      //Now we now what type of sound to play and at what speed.
// Change the sample if needed

    if (AdvertPlaying==0)     // If no advert/horn then we chan change gear, else skip until finished
    {
      if (Scaled_V>NAVY_DIESEL_LOWER && Scaled_V<NAVY_DIESEL_UPPER)
      {
          Sounds=NavyDiesel;
          CurrentSound=SpeedIndex[Sounds][CurrentGear];
      
          if(CurrentSound!=PreviousSound)
          {
            myMP3.loop(CurrentSound);
          } 
          PreviousSound=CurrentSound;
      }
      
      else if (Scaled_V>TUG_DIESEL_LOWER && Scaled_V<TUG_DIESEL_UPPER)
      {
          Sounds=TugDiesel;
          CurrentSound=SpeedIndex[Sounds][CurrentGear];
        
          if(CurrentSound!=PreviousSound)
          {
            myMP3.loop(CurrentSound);
          }
          PreviousSound=CurrentSound;
      }
  
      else if (Scaled_V>STEAM_1_LOWER && Scaled_V<STEAM_1_UPPER)
      {
          Sounds=SteamBoat1;
          CurrentSound=SpeedIndex[Sounds][CurrentGear];
       
          if(CurrentSound!=PreviousSound)
          {  
              myMP3.loop(CurrentSound);
          }
          PreviousSound=CurrentSound;          
      }
      
      else if (Scaled_V>STEAM_2_LOWER && Scaled_V<STEAM_2_UPPER)
      {
          Sounds=SteamBoat2;
          CurrentSound=SpeedIndex[Sounds][CurrentGear];
       
          if(CurrentSound!=PreviousSound)
          {  
              myMP3.loop(CurrentSound);
          }
          PreviousSound=CurrentSound;      
      }
      
    }// End if Advertplaying==0
    PlayHorn();   // See if we need to change to a horn sound effect.
    //RunTime=millis();
    #ifdef DEBUG
    mySerial.print("millis=");
    mySerial.print(millis());
    mySerial.print("RunTime= ");
    mySerial.println(RunTime);
    #endif
    if (millis()>RunTime + 1000)  // >1000ms since last check.
    {
      PWMFound=CheckforPWMInputs();        // Update current PWM inputs.
      RunTime=millis();           // Set new runtime expiry
    }
    #ifdef DEBUG
    delay(350);
    mySerial.print(F("AdvertPlaying= "));
    mySerial.println(AdvertPlaying);
    mySerial.print(F("Throttle= "));
    mySerial.println(ThrottlePWM);
    mySerial.print(F("Horn= "));
    mySerial.println(HornPWM);
    #endif


}// End loop()

void BlinkLED(byte numTimes, word ontime, word offtime)
{
  byte numblinks=0;
  while(numblinks<numTimes)
  {
      digitalWrite(LEDPIN,LEDON);
      delay(ontime);
      digitalWrite(LEDPIN,LEDOFF);
      delay(offtime);
      numblinks++;
  }    
  
}

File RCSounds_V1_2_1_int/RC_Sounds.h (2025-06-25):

/*
 * RC_Sounds.h
 * This provides all the configuration for the RC_Sounds software.
 */


#define LEDPIN        PB2
#define HORN_IN       PB0
#define SELECTION_IN  A0
#define THROTTLE_IN   PB1
#define LEDON         LOW
#define LEDOFF        HIGH
#define SWITCHCLOSED  0x77
#define SWITCHOPEN    0x66


/*
 * These defines might seem extraneous but they allow easier configuration if the code is used for Boats, Cars/Trucks
 * or trains. They are compile time directives and only the code defined gets built.
 */

#define BOAT
//#define CAR
/* Constants for Sound effect selection these are the scaled voltages seen at the input with +/-0.15V tolerance.
 *  All calculated values for reference
 *  Switch(es)  Equivalent resistance   Upper limit   Nominal   Lower limit
 *  None        100K                    4.69V         4.54V     4.39V
 *  S4          31.972K                 4.05V         3.90V     3.75V
 *  S3          15.27K                  3.50V         3.35V     3.20V
 *  S2          9.09K                   2.65V         2.50V     2.35V            
 *  S1          4.48K                   1.85V         1.70V     1.55V
 *  S5          2.15K                   1.03V         0.88V     0.73V
 *  S4+S3                               3.15V         3.00V     2.85V    
 *  S4+S2                               2.50V         2.35V     2.20V
 *  S3+S2                               2.30V         2.15V     2.00V       
 *  
 */
#ifdef BOAT
const int NAVY_DIESEL_UPPER =  961;        
const int NAVY_DIESEL_LOWER =  899;      // 4.69 to 4.39V All switches open
const int TUG_DIESEL_UPPER  =  829;    // S4 only closed 4.05V to 3.75V
const int TUG_DIESEL_LOWER  =  780;    
const int STEAM_1_UPPER     =  717;    // S3 only closed
const int STEAM_1_LOWER     =  655;    
const int STEAM_2_UPPER     =  543;    // S2 only closed
const int STEAM_2_LOWER     =  481;

//const int MIN_PULSE=750;
//const int MAX_PULSE=2500;

enum Sound_Effect_Type{NavyDiesel=0,TugDiesel=1,SteamBoat1=2,SteamBoat2=3,None=99};
/*
 * Multi-dimensional array to pick the sound effect played. 
 * Column 0 is the default set of sounds i.e. idle, column 1 is 1st gear, column 2 is 2nd gear, column 3 is 3rd gear, column 4 is 4th gear
 * Row 0 is Navy diesel, Row 1 is Tug diesel, Row 2 is Steam boat, Row 3 is Steam launch.
 * This same array, used as a lookup table, also selects the horn sound.
 * So Navy diesel sound #5, for example, would select Advert #5 if needed, which blends sample #5 with the horn
 */
byte SpeedIndex[4][5]={
                        {1,2,3,4,5},        // Navy diesel sounds
                        {6,7,8,9,10},       // Tug diesel sounds
                        {11,12,13,14,15},   // Steam boat 1 sounds
                        {16,17,18,19,20}    // Steam boat 2 sounds
};
#endif
/*
 * This sets the samples/type for Car/truck sounds
 */
#ifdef CAR


enum Sound_Effect_Type{none=0,RegularCar,V8Car,MuscleCar,DieselTruck};

#endif 


/* The setup switch, S5 is regardless of output type and the values shown allow for S1-S4 closed in paralllel
   or just S5 closed on its own.
*/
#ifdef DEBUGPROG
//Test settings using S4 closed and push switch across S3, save changing fuses for testing.
const int SETUP_UPPER       =  645;   // 3.15V to 2.85V
const int SETUP_LOWER       =  584;
#else
const int SETUP_UPPER       =  211;       //1.03V to 0.49V
const int SETUP_LOWER       =  100;
#endif


enum Sound_Effect_Type Sounds=None;
//Globals to hold the ADC sampled value and the converted voltage.
unsigned int Scaled_V;
//Used when reading servo pulse input
unsigned int HornPulseLimit=0;
unsigned int FirstGear,SecondGear,ThirdGear,FourthGear;
unsigned int ForwardThrot, NeutralThrot, ReverseThrot;
byte HornGreatOrLessThan, ThrotNormReverse;
byte CurrentGear;
// Set the hysteresis of the gear change
const byte GearHysteresis=25;


// To control the Advert timing
byte CurrentSound,PreviousSound;
byte CurrentAdvert=0,PreviousAdvert=0;
byte AdvertPlaying=0;
unsigned long AdTime=0;
// Globals that hold the current PWM values
unsigned int ThrottlePWM,HornPWM;
//Global that denotes what signals are present
byte PWMFound;

const byte numReadings=4;
unsigned int readings[numReadings];
byte readIndex=0;
unsigned int total=0;

unsigned long RunTime=0;

//Throttle globals
unsigned int ThrottlePosition=0;
// Settings related to servo pulse positions
#define GREATERTHAN             0x33
#define LESSTHAN                0x22
#define NORMAL_THROT            0x34
#define REVERSE_THROT           0x23
#define HORN_EEPROM_LO          0
#define HORN_EEPROM_HI          1
#define HORN_EEPROM_GT_LT       2
#define THROT_EEPROM_FORWARD_LO 3
#define THROT_EEPROM_FORWARD_HI 4
#define THROT_EEPROM_NEUTRAL_LO 5
#define THROT_EEPROM_NEUTRAL_HI 6
#define THROT_EEPROM_REVERSE_LO 7
#define THROT_EEPROM_REVERSE_HI 8
#define THROT_EEPROM_DIRECTION  9
// For EEPROM setup
#define E_INIT 256



#define TimerAdjustment 27   //27us to allow for servo pulse jitter and detent of radio

#define DEBOUNCETIME 200

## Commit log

2021-06-12 Add files via upload
    Corrected error in analogue input connection in schematic and PCB.
    [RC_Sounds.kicad_pcb, RC_Sounds.sch]
2021-06-12 Add files via upload
    My current SD Card image. Files came from, https://sound-effects.bbcrewind.co.uk/ & https://freesound.org/. Horn sound mixed using my normal process.
2022-06-05 Add files via upload
    This fixes multiple issues:
    1) If the unit was externally powered (not via BEC), there was no horn input and it looked for <VALUE to operate, the horn would continually sound.
    2) The gear change was like a dodgy automatic, going up/down around the trigger points. Moving average filter + hysteresis fixed this.
    3) Sometimes the 'advert' used to play the horn, was cut off, added new code to fix this, now using a 13 second delay. Will improve in next release.
    4) Reduced the loop time from ~250ms to 32ms, this helped the averaging filter respond quicker and is more efficient. The Pulsein() function is a paint.
    [RCSounds_V1.2_test.ino, RC_Sounds.h]
2022-06-07 Update README.md
    Added notes on powering the design.
